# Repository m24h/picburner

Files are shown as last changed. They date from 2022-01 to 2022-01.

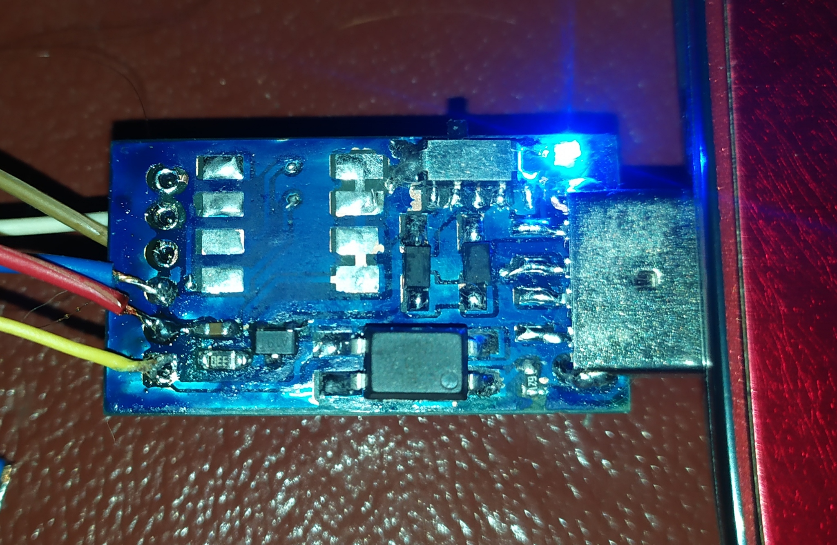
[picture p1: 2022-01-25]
running/board.jpg

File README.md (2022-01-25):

# picburner
a JDM/icprog/ponyprog compatible/modified hardware for burning PICs and other I2C SPI devices.

features:

1. With USB interface.
2. Using a charge pump to provide high voltage for programming, no other power supply needed.
3. Similar logic as JDM/SI-Prog hardware, Compatible with icprog/ponyprog software
4. ICSP compatible connector with modified signal for I2C/SPI devices burning
5. Compatible with 3.3V/5V devices
6. Providing several commonly used programming voltage, and current-limited VPP ouput for clamping outside
7. Circuit is very simple for DIY

issues:

1. I don't know why icprog failed in reading/writing 93CXX devices but ponyprog succeeds

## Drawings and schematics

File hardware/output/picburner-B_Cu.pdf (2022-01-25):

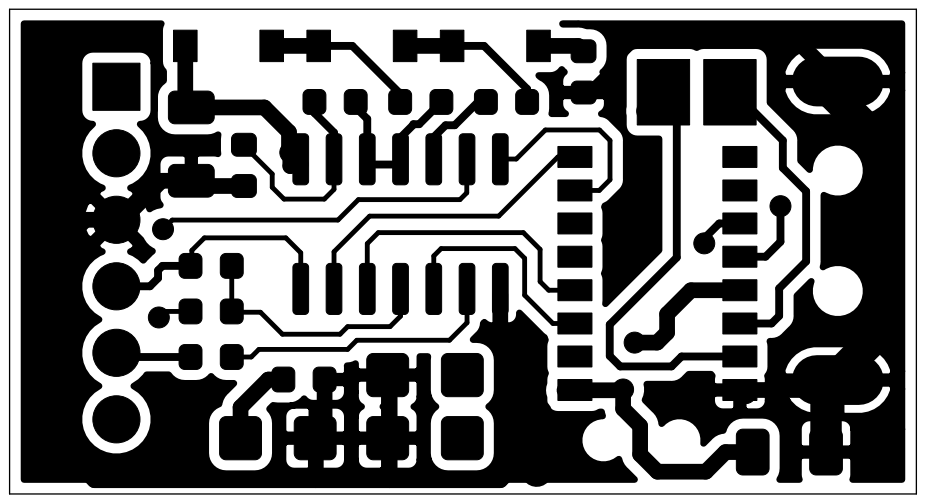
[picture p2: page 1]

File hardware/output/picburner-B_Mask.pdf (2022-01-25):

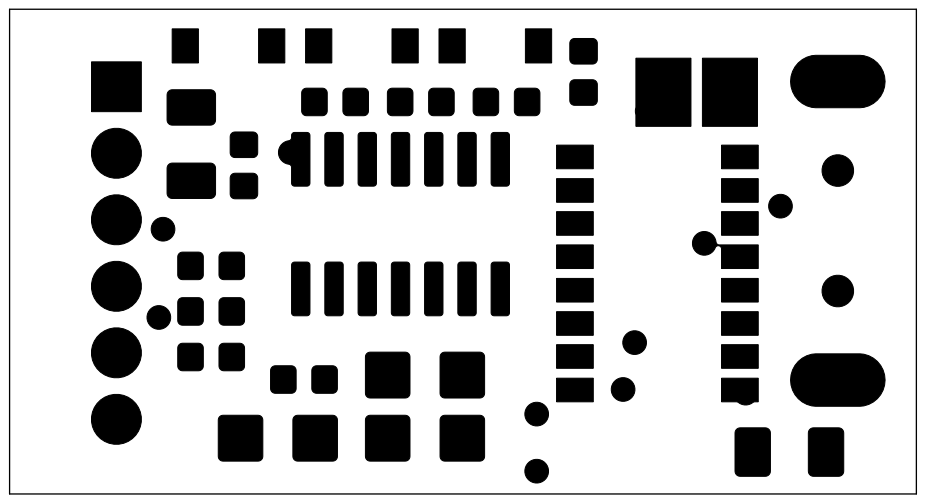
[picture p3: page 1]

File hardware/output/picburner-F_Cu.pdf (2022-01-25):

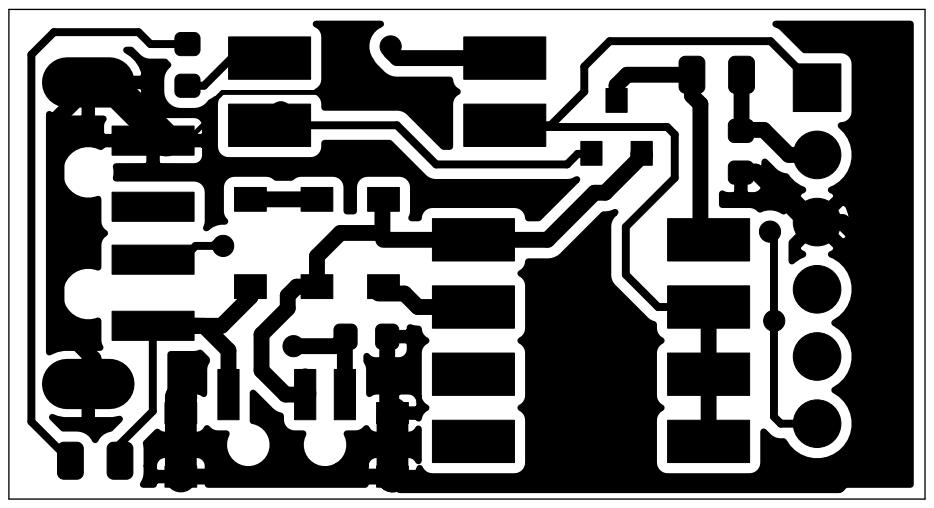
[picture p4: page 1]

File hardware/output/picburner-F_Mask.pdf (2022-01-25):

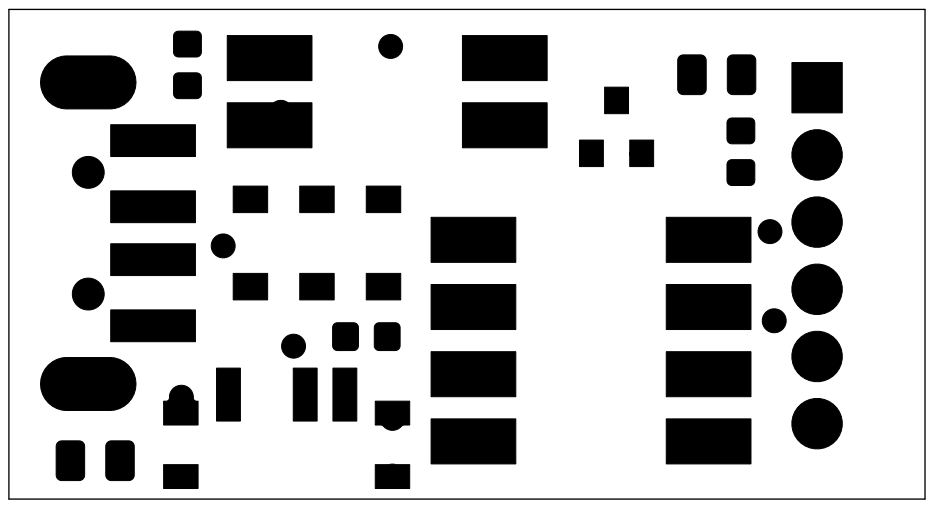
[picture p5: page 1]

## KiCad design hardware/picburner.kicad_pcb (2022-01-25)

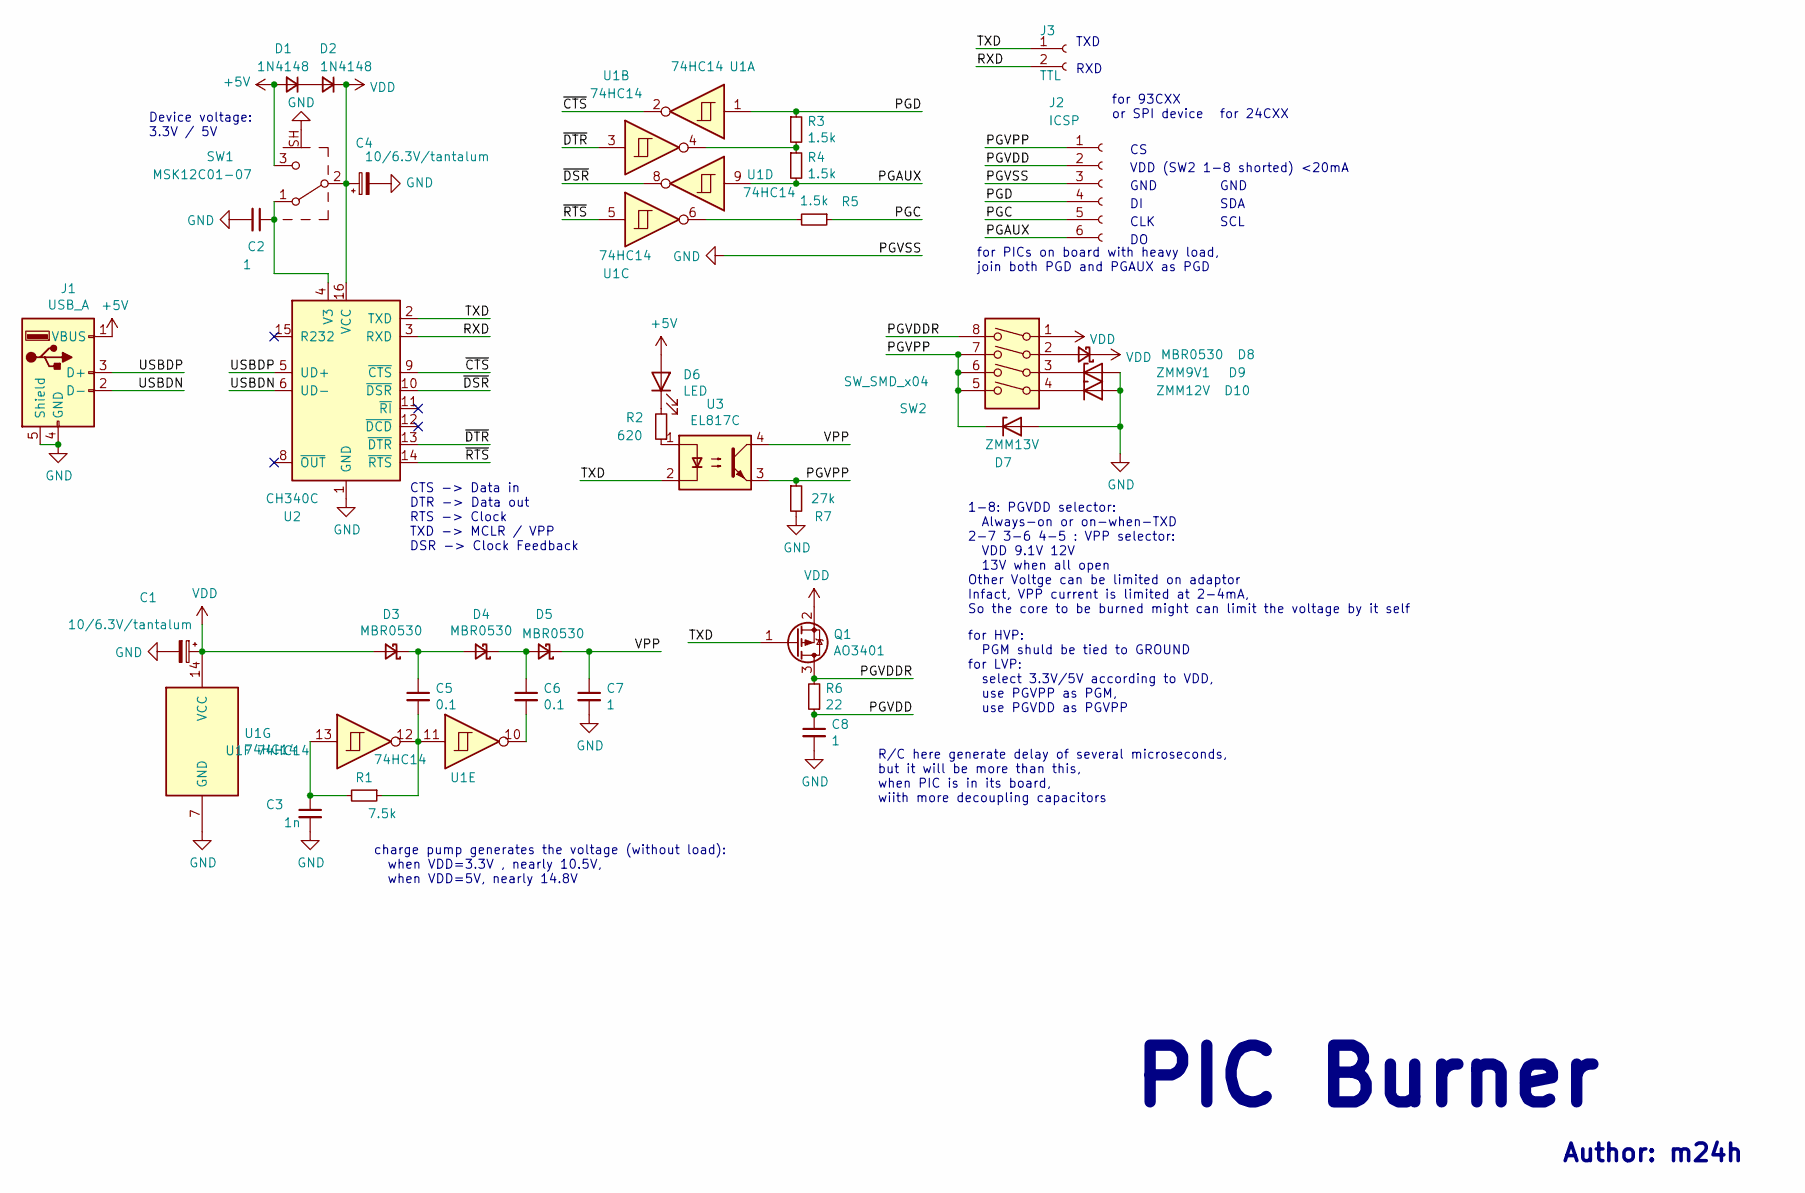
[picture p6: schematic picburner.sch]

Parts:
C1, C4: 10/6.3V/tantalum; C_1206_3216Metric
C2, C7, C8: 1; C_0603_1608Metric
C3: 1n; C_0603_1608Metric
C5, C6: 0.1; C_0603_1608Metric
D1, D2: 1N4148; D_SOD-123
D3, D4, D5, D8: MBR0530; D_SOD-123
D6: LED; LED_0805_2012Metric
D7: ZMM13V; D_1206_3216Metric_Castellated
D9: ZMM9V1; D_1206_3216Metric_Castellated
D10: ZMM12V; D_1206_3216Metric_Castellated
J1: USB_A; USB_A_CNCTech_1001-011-01101_Horizontal
J2: ICSP; PinHeader_1x06_P2.54mm_Horizontal
J3: TTL; 2PAD_1x02_P2.54mm_SMD
Q1: AO3401; SOT-23
R1: 7.5k; R_0603_1608Metric
R2: 620; R_0603_1608Metric
R3, R4, R5: 1.5k; R_0603_1608Metric
R6: 22; R_0805_2012Metric
R7: 27k; R_0603_1608Metric
SW1: MSK12C01-07
SW2: SW_SMD_x04; DIP-8_W8.89mm_SMDSocket_LongPads
U1: 74HC14; SOIC-14_3.9x8.7mm_P1.27mm
U2: CH340C; SOP-16_4.4x10.4mm_P1.27mm
U3: EL817C; DIP-4_W8.89mm_SMDSocket_LongPads

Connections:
+5V: D1.2 (A), D6.2 (A), J1.1 (VBUS), SW1.3 (C)
/PGAUX: J2.6, R4.2, U1.9
/PGC: J2.5, R5.1
/PGD: J2.4, R3.1, U1.1
/PGVDD: C8.1, J2.2, R6.1
/PGVDDR: Q1.3 (D), R6.2, SW2.8
/PGVPP: D7.1 (K), J2.1, R7.1, SW2.5, SW2.6, SW2.7, U3.3
/RXD: J3.2, U2.3 (RXD)
/TXD: J3.1, Q1.1 (G), U2.2 (TXD), U3.2
/USBDN: J1.2 (D-), U2.6 (UD-)
/USBDP: J1.3 (D+), U2.5 (UD+)
/VPP: C7.1, D5.1 (K), U3.4
/~CTS: U1.2, U2.9 (~CTS)
/~DSR: U1.8, U2.10 (~DSR)
/~DTR: U1.3, U2.13 (~DTR)
/~RTS: U1.5, U2.14 (~RTS)
GND: C1.2, C2.2, C3.2, C4.2, C7.2, C8.2, D7.2 (A), D9.2 (A), D10.2 (A), J1.4 (GND), J1.5 (Shield), J2.3, R7.2, SW1.SH (Shield), U1.7 (GND), U2.1 (GND)
unnamed: C2.1, SW1.1 (A), U2.4 (V3)
unnamed: C3.1, R1.2, U1.13
unnamed: C5.1, D3.1 (K), D4.2 (A)
unnamed: C5.2, R1.1, U1.11, U1.12
unnamed: C6.1, D4.1 (K), D5.2 (A)
unnamed: C6.2, U1.10
unnamed: D1.1 (K), D2.2 (A)
unnamed: D6.1 (K), R2.2
unnamed: D8.2 (A), SW2.2
unnamed: D9.1 (K), SW2.3
unnamed: D10.1 (K), SW2.4
unnamed: R2.1, U3.1
unnamed: R3.2, R4.1, U1.4
unnamed: R5.2, U1.6
VDD: C1.1, C4.1, D2.1 (K), D3.2 (A), D8.1 (K), Q1.2 (S), SW1.2 (B), SW2.1, U1.14 (VCC), U2.16 (VCC)

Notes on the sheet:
CTS -> Data in DTR -> Data out RTS -> Clock TXD -> MCLR / VPP DSR -> Clock Feedback
Device voltage: 3.3V / 5V
1-8: PGVDD selector: Always-on or on-when-TXD 2-7 3-6 4-5 : VPP selector: VDD 9.1V 12V 13V when all open Other Voltge can be limited on adaptor Infact, VPP current is limited at 2-4mA, So the core to be burned might can limit the voltage by it self
for HVP: PGM shuld be tied to GROUND for LVP: select 3.3V/5V according to VDD, use PGVPP as PGM, use PGVDD as PGVPP
PIC Burner
Author: m24h
R/C here generate delay of several microseconds, but it will be more than this, when PIC is in its board, wiith more decoupling capacitors
charge pump generates the voltage (without load): when VDD=3.3V , nearly 10.5V, when VDD=5V, nearly 14.8V
CLK
for 93CXX or SPI device
for 24CXX
GND
VDD (SW2 1-8 shorted) <20mA
SCL
SDA
for PICs on board with heavy load, join both PGD and PGAUX as PGD
TXD
RXD

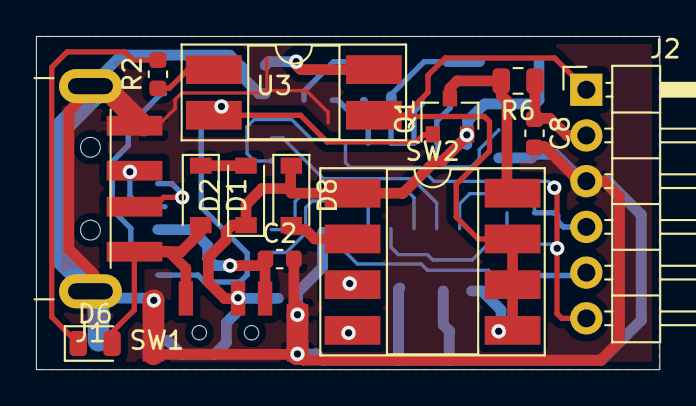
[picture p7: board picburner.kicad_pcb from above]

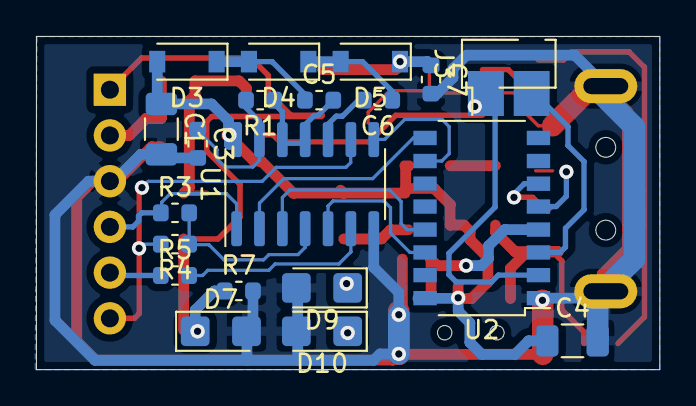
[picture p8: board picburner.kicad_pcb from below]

Board: 2 copper layers, 34.6 x 18.5 mm, 34 parts (20 on the bottom side), 32 nets.
